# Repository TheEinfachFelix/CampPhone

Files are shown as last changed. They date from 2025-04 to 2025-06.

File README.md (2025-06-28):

# CampPhone

https://wolles-elektronikkiste.de/sim800l-modul

Gruppen Anruf
https://stackoverflow.com/questions/60790790/how-can-i-start-a-conference-call-on-gsm-network

Datasheet
https://www.makershop.de/download/Datasheet_SIM800L.pdf

Infos zu sim800L
https://dasraspberrypi.de/sim800l-gsm-gps-raspberry-4/

Sim 1:  4915756785137

Warum habe ich mich dagegen entschieden, das Sim Modul selber zu implementieren? Ich habe kein Chip gefunden, der günstiger als das fertige Modul war, und ein Datenblatt in Englischer Sprache hat.

GPS Module:
https://www.lcsc.com/product-detail/GNSS-Modules_ZHONGKEWEI-ATGM336H-5N31_C90770.html

Doku Dazu
https://medium.com/@joshhrisko/portable-gps-tracker-with-arduino-3affead7ba12
Ne lib dazu
https://github.com/mikalhart/TinyGPSPlus

Zum Display
https://buyepaper.com/products/27-inch-e-ink-touch-screen-spi-interface-4-grayscale-gdey027t91-t01
https://de.aliexpress.com/item/1005004887416350.html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!!!

Daten
https://www.good-display.com/product/259.html

FT6336U Touch Chip

Hier ne lib fürs display
https://github.com/ZinggJM/GxEPD2

Und fürs Touch
https://github.com/aselectroworks/Arduino-FT6336U

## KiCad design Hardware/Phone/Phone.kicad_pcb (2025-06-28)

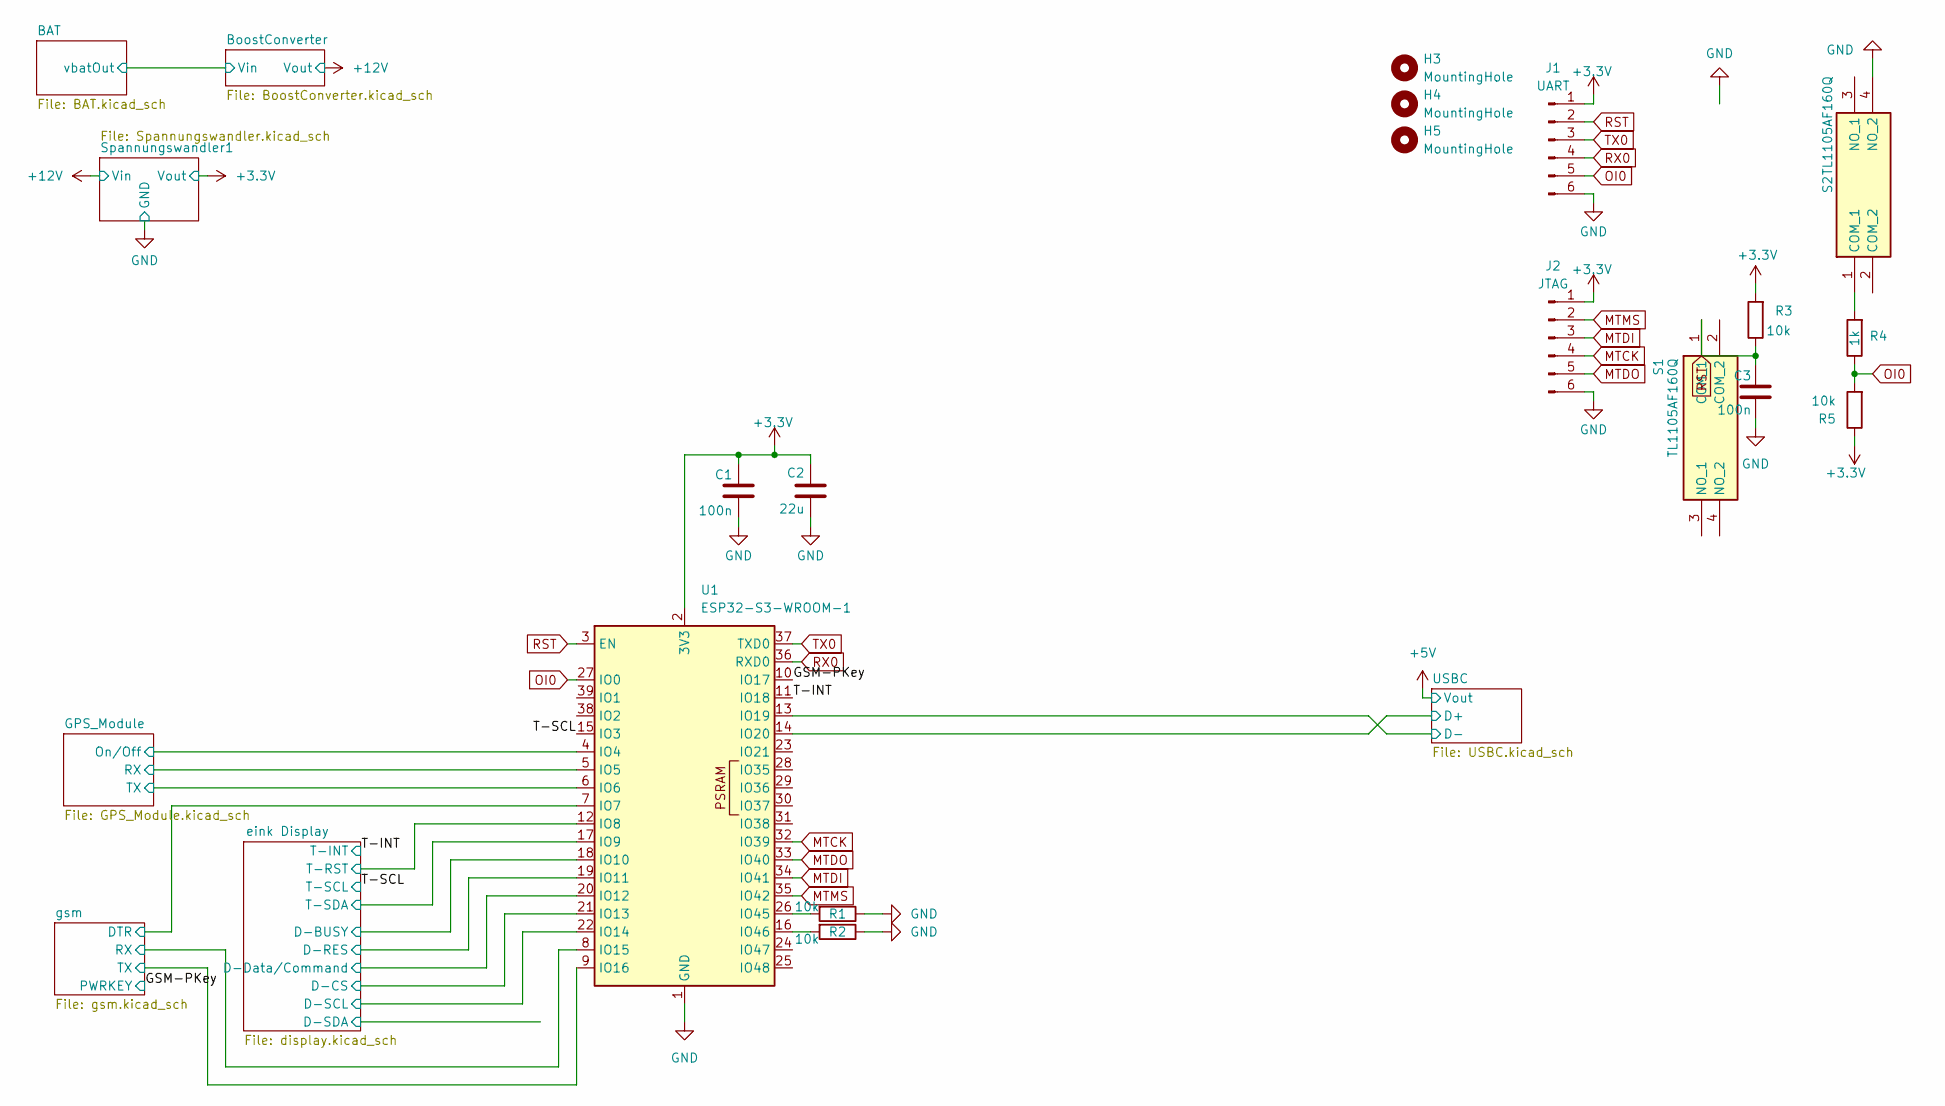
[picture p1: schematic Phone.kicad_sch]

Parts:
C1, C3: 100n; C_0603_1608Metric
C2: 22u; C_0603_1608Metric
H3, H4, H5: MountingHole; MountingHole_3.2mm_M3
J1: UART; 490107670612
J2: JTAG; 490107670612
R1, R2, R3, R5: 10k; R_0603_1608Metric
R4: 1k; R_0603_1608Metric
S1, S2: TL1105AF160Q; Mouser Part Number 612-TL1105A
U1: ESP32-S3-WROOM-1; ESP32-S3-WROOM-1U

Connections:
+3.3V: C1.2, C2.2, J1.1, J2.1, R3.2, R5.1, U1.2 (3V3); also elsewhere on the board
/GPS_Module/On/Off: U1.4 (IO4); also elsewhere on the board
/GPS_Module/RX: U1.5 (IO5); also elsewhere on the board
/GPS_Module/TX: U1.6 (IO6); also elsewhere on the board
/GSM-PKey: U1.10 (IO17); also elsewhere on the board
/T-INT: U1.11 (IO18); also elsewhere on the board
/T-SCL: U1.15 (IO3); also elsewhere on the board
/USBC/D+: U1.14 (IO20); also elsewhere on the board
/USBC/D-: U1.13 (IO19); also elsewhere on the board
/eink Display/D-BUSY: U1.18 (IO10); also elsewhere on the board
/eink Display/D-CS: U1.21 (IO13); also elsewhere on the board
/eink Display/D-Data/Command: U1.20 (IO12); also elsewhere on the board
/eink Display/D-RES: U1.19 (IO11); also elsewhere on the board
/eink Display/D-SCL: U1.22 (IO14); also elsewhere on the board
/eink Display/T-RST: U1.12 (IO8); also elsewhere on the board
/eink Display/T-SDA: U1.17 (IO9); also elsewhere on the board
/gsm/DTR: U1.7 (IO7); also elsewhere on the board
/gsm/RX: U1.8 (IO15); also elsewhere on the board
/gsm/TX: U1.9 (IO16); also elsewhere on the board
GND: C1.1, C2.1, C3.1, J1.6, J2.6, R1.1, R2.1, S2.4 (NO_2), U1.1 (GND), U1.40 (GND), U1.41 (GND); also elsewhere on the board
MTCK: J2.4, U1.32 (IO39)
MTDI: J2.3, U1.34 (IO41)
MTDO: J2.5, U1.33 (IO40)
MTMS: J2.2, U1.35 (IO42)
unnamed: R4.2, S2.1 (COM_1)
unnamed: R1.2, U1.26 (IO45)
unnamed: R2.2, U1.16 (IO46)
OI0: J1.5, R4.1, R5.2, U1.27 (IO0)
RST: C3.2, J1.2, R3.1, S1.1 (COM_1), U1.3 (EN)
RX0: J1.4, U1.36 (RXD0)
TX0: J1.3, U1.37 (TXD0)

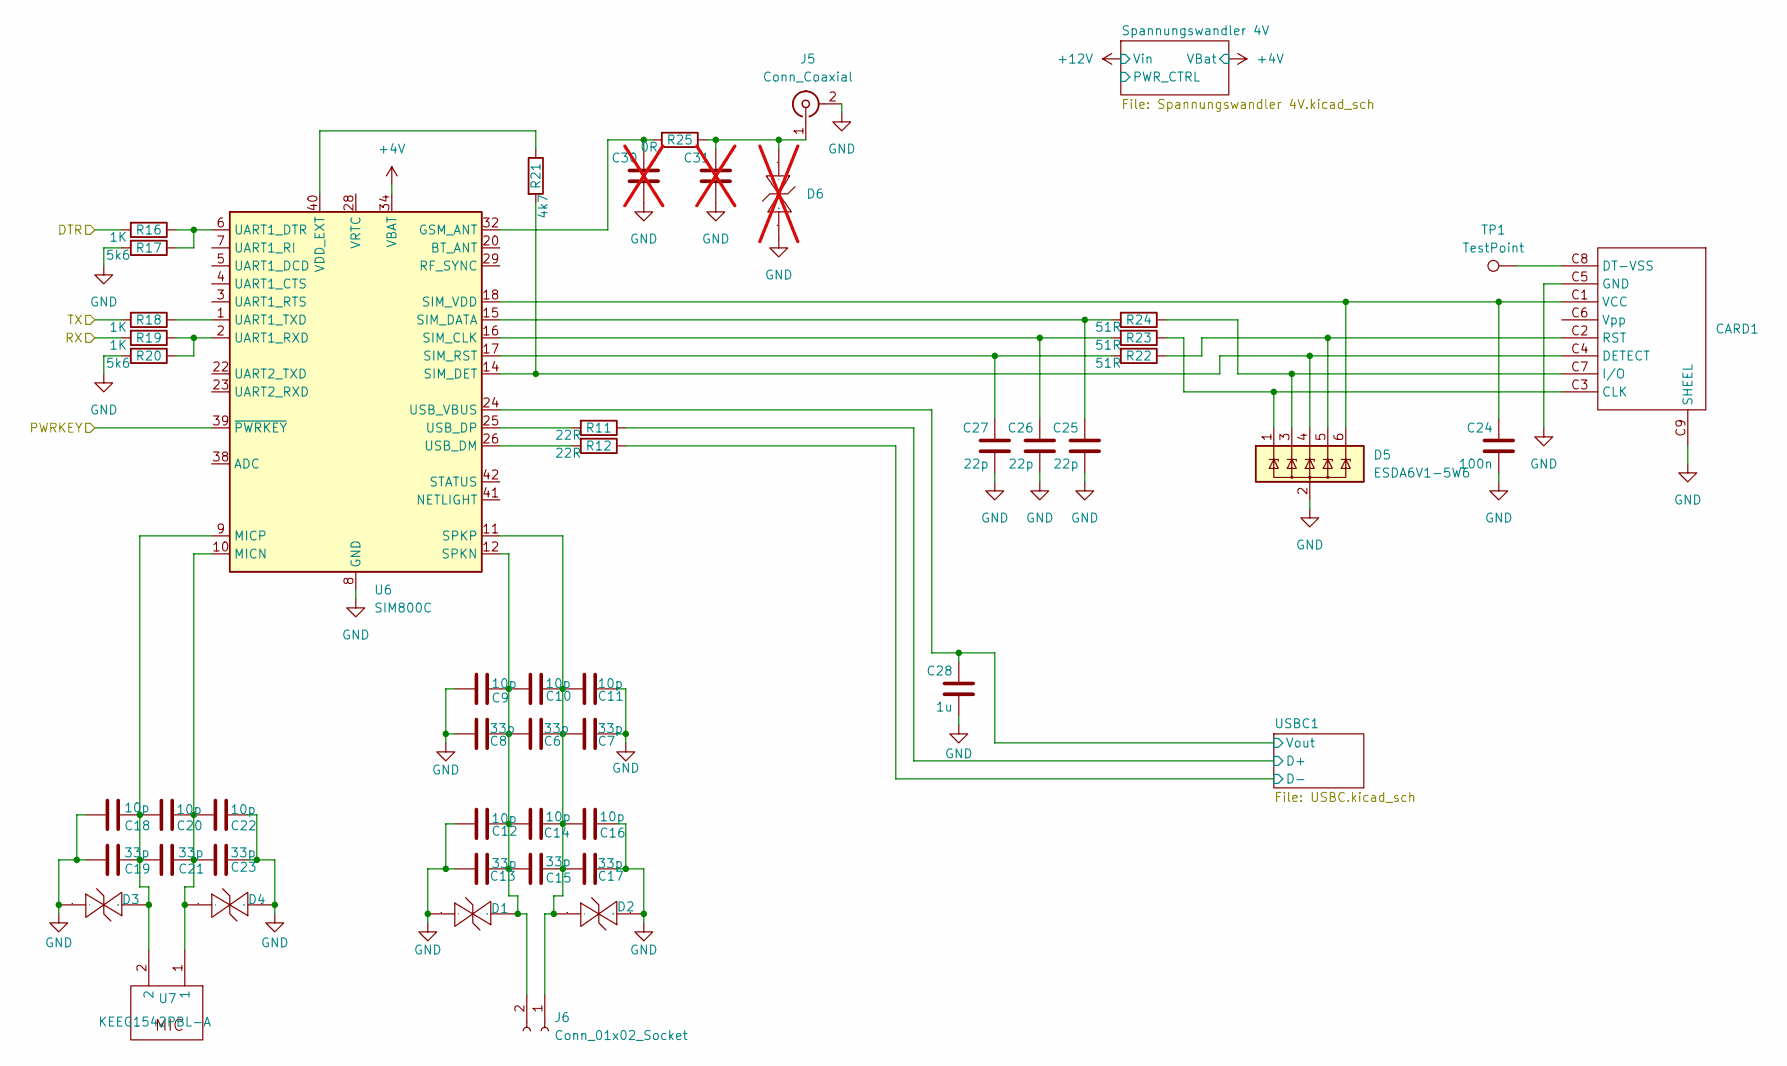
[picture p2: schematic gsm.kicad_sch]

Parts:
C6, C7, C8, C13, C15, C17, C19, C21, C23: 33p; C_0603_1608Metric
C9, C10, C11, C12, C14, C16, C18, C20, C22: 10p; C_0603_1608Metric
C24: 100n; C_0603_1608Metric
C25, C26, C27: 22p; C_0603_1608Metric
C28: 1u; C_0603_1608Metric
C30, C31: C_0603_1608Metric; not fitted
CARD1: SIM-SMD_503960-0696
D1, D2, D3, D4: SOD-882_L1.0-W0.6-BI
D5: ESDA6V1-5W6; SOT-363_SC-70-6
D6: SOD-882_L1.0-W0.6-BI; not fitted
J5: Conn_Coaxial; U.FL_Hirose_U.FL-R-SMT-1_Vertical
J6: Conn_01x02_Socket; PinHeader_1x02_P2.54mm_Vertical
R11, R12: 22R; R_0603_1608Metric
R16, R18, R19: 1K; R_0603_1608Metric
R17, R20: 5k6; R_0603_1608Metric
R21: 4k7; R_0603_1608Metric
R22, R23, R24: 51R; R_0603_1608Metric
R25: 0R; R_0603_1608Metric
TP1: TestPoint; TestPoint_Pad_D1.0mm
U6: SIM800C; SIMCom_SIM800C
U7: KEEG1542PBL-A; MIC-TH_BD4.0-P1.40_KEEG1542PBL-A

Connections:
+4V: U6.34 (VBAT), U6.35 (VBAT); also elsewhere on the board
/GSM-PKey: U6.39 (~PWRKEY); also elsewhere on the board
/gsm/DTR: R16.2; also elsewhere on the board
/gsm/RX: R19.2; also elsewhere on the board
/gsm/TX: R18.2; also elsewhere on the board
/gsm/USBC1/D+: R11.1; also elsewhere on the board
/gsm/USBC1/D-: R12.1; also elsewhere on the board
/gsm/USBC1/Vout: C28.2, U6.24 (USB_VBUS); also elsewhere on the board
GND: C7.1, C8.2, C9.2, C11.1, C12.2, C13.2, C16.1, C17.1, C18.2, C19.2, C22.1, C23.1, C24.1, C25.1, C26.1, C27.1, C28.1, C30.1, C31.1, CARD1.C5 (GND), CARD1.C9 (SHEEL), D1.1 (C), D2.2 (A), D3.1 (C), D4.2 (A), D5.2 (GND), D6.2 (A), J5.2 (Ext), R17.2, R20.2, U6.8 (GND), U6.13 (GND), U6.19 (GND), U6.21 (GND), U6.27 (GND), U6.30 (GND), U6.31 (GND), U6.33 (GND), U6.36 (GND), U6.37 (GND); also elsewhere on the board
unnamed: CARD1.C3 (CLK), D5.1 (IO1), R23.1
unnamed: CARD1.C4 (DETECT), D5.4 (IO3), R21.2, U6.14 (SIM_DET)
unnamed: CARD1.C8 (DT-VSS), TP1.1
unnamed: CARD1.C7 (I/O), D5.3 (IO2), R24.1
unnamed: CARD1.C2 (RST), D5.5 (IO4), R22.1
unnamed: C24.2, CARD1.C1 (VCC), D5.6 (IO5), U6.18 (SIM_VDD)
unnamed: C6.2, C8.1, C9.1, C10.2, C12.1, C13.1, C14.2, C15.2, D1.2 (A), J6.2, U6.12 (SPKN)
unnamed: C6.1, C7.2, C10.1, C11.2, C14.1, C15.1, C16.2, C17.2, D2.1 (C), J6.1, U6.11 (SPKP)
unnamed: C18.1, C19.1, C20.2, C21.2, D3.2 (A), U6.9 (MICP), U7.2
unnamed: C20.1, C21.1, C22.2, C23.2, D4.1 (C), U6.10 (MICN), U7.1
unnamed: C31.2, D6.1 (C), J5.1 (In), R25.1
unnamed: C30.2, R25.2, U6.32 (GSM_ANT)
unnamed: C26.2, R23.2, U6.16 (SIM_CLK)
unnamed: C25.2, R24.2, U6.15 (SIM_DATA)
unnamed: C27.2, R22.2, U6.17 (SIM_RST)
unnamed: R16.1, R17.1, U6.6 (UART1_DTR)
unnamed: R19.1, R20.1, U6.2 (UART1_RXD)
unnamed: R18.1, U6.1 (UART1_TXD)
unnamed: R12.2, U6.26 (USB_DM)
unnamed: R11.2, U6.25 (USB_DP)
unnamed: R21.1, U6.40 (VDD_EXT)

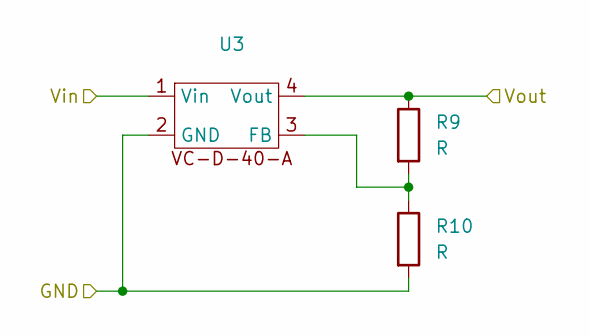
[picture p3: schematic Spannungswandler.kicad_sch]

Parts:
R9, R10: R; R_0805_2012Metric_Pad1.20x1.40mm_HandSolder
U3: VC-D-40-A

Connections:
+3.3V: R9.1, U3.4 (Vout); also elsewhere on the board
+12V: U3.1 (Vin); also elsewhere on the board
GND: R10.2, U3.2 (GND); also elsewhere on the board
unnamed: R9.2, R10.1, U3.3 (FB)

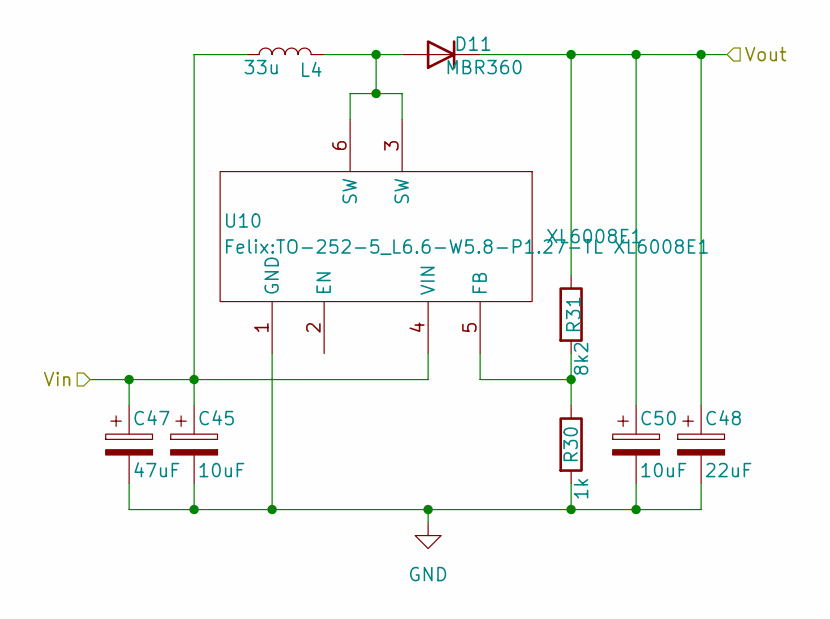
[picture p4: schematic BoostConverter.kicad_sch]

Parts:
C45, C50: 10uF; CP_Elec_4x5.4
C47: 47uF; CP_Elec_6.3x7.7
C48: 22uF; CP_Elec_10x10
D11: MBR360; TO-252-2
L4: 33u; L_7.3x7.3_H4.5
R30: 1k; R_0603_1608Metric
R31: 8k2; R_0603_1608Metric
U10: XL6008E1; TO-252-5_L6.6-W5.8-P1.27-TL XL6008E1

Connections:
+12V: C48.1, C50.1, D11.1 (K), R31.1; also elsewhere on the board
/BAT/vbatOut: C45.1, C47.1, L4.1, U10.4 (VIN); also elsewhere on the board
GND: C45.2, C47.2, C48.2, C50.2, R30.2, U10.1 (GND); also elsewhere on the board
unnamed: D11.2 (A), L4.2, U10.3 (SW), U10.6 (SW)
unnamed: R30.1, R31.2, U10.5 (FB)

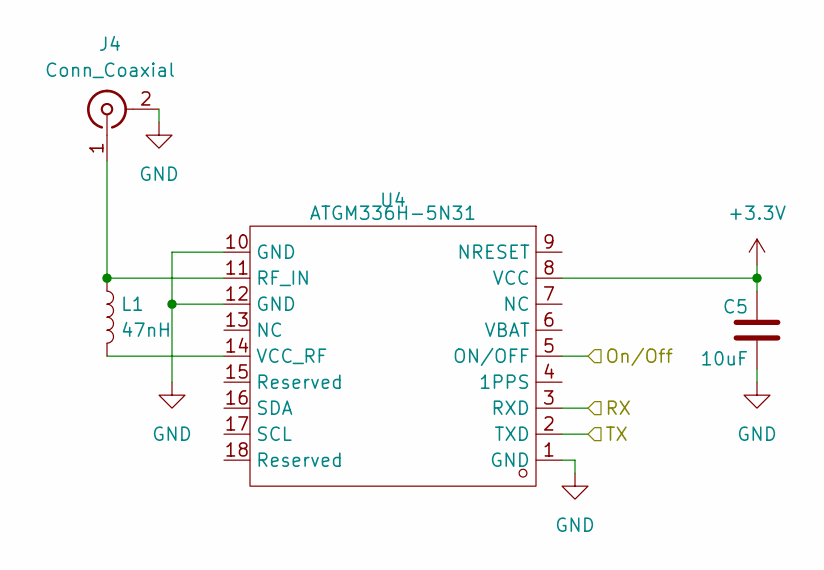
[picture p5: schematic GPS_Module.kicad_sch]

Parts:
C5: 10uF; C_0603_1608Metric
J4: Conn_Coaxial; U.FL_Hirose_U.FL-R-SMT-1_Vertical
L1: 47nH; L_0805_2012Metric
U4: ATGM336H-5N31; GPSM-SMD_ATGM336H-TR

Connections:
+3.3V: C5.2, U4.8 (VCC); also elsewhere on the board
/GPS_Module/On/Off: U4.5 (ON/OFF); also elsewhere on the board
/GPS_Module/RX: U4.3 (RXD); also elsewhere on the board
/GPS_Module/TX: U4.2 (TXD); also elsewhere on the board
GND: C5.1, J4.2 (Ext), U4.1 (GND), U4.10 (GND), U4.12 (GND); also elsewhere on the board
unnamed: J4.1 (In), L1.1, U4.11 (RF_IN)
unnamed: L1.2, U4.14 (VCC_RF)

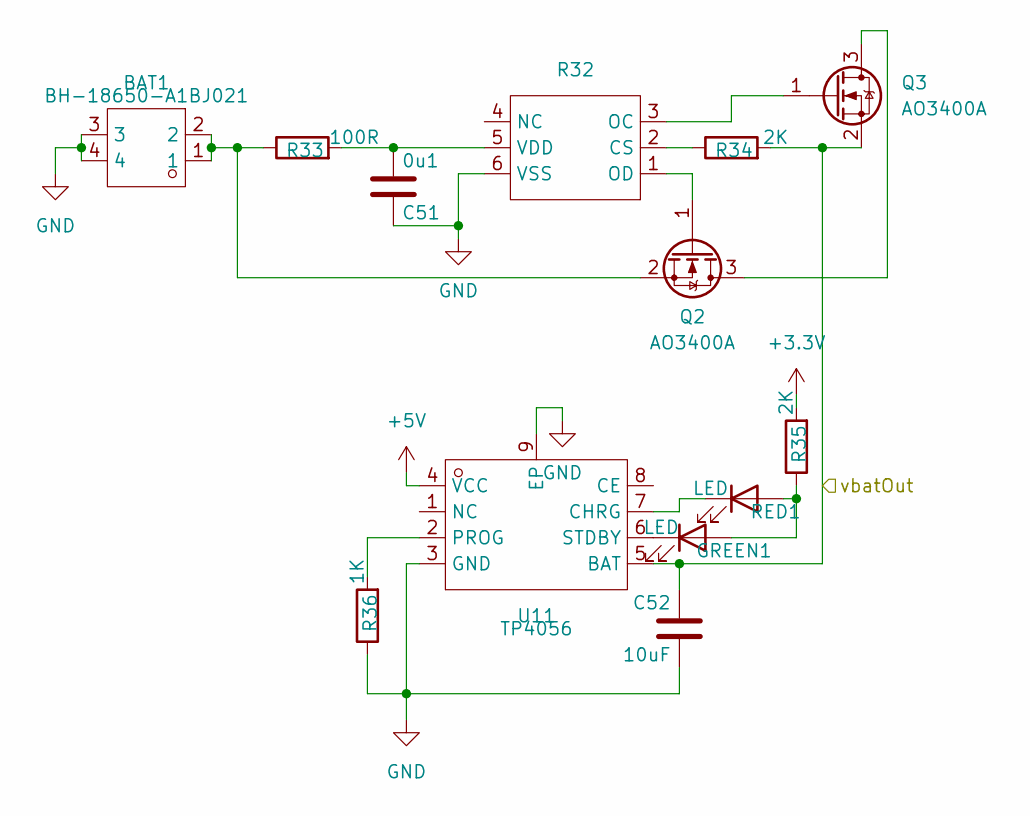
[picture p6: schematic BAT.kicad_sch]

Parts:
BAT1: BH-18650-A1BJ021; BAT-TH_L77.0-W39.9_BH-18650-A1BJ021
C51: 0u1; C_0603_1608Metric
C52: 10uF; C_0603_1608Metric
GREEN1: LED; LED_0603_1608Metric
Q2, Q3: AO3400A; SOT-23
R32: SOT-23-6_L2.9-W1.6-P0.95-LS2.8-BR FM2113
R33: 100R; R_0603_1608Metric
R34, R35: 2K; R_0603_1608Metric
R36: 1K; R_0603_1608Metric
RED1: LED; LED_0603_1608Metric
U11: TP4056; ESOP-8_L4.9-W3.9-P1.27-LS6.0-BL-EP

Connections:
+3.3V: R35.2; also elsewhere on the board
+5V: U11.4 (VCC); also elsewhere on the board
/BAT/vbatOut: C52.2, Q3.2 (S), R34.2, U11.5 (BAT); also elsewhere on the board
GND: BAT1.3, BAT1.4, C51.2, C52.1, R32.6 (VSS), R36.1, U11.3 (GND), U11.9 (EP); also elsewhere on the board
unnamed: GREEN1.2 (A), R35.1, RED1.2 (A)
unnamed: GREEN1.1 (K), U11.6 (STDBY)
unnamed: Q2.3 (D), Q3.3 (D)
unnamed: Q2.1 (G), R32.1 (OD)
unnamed: BAT1.1, BAT1.2, Q2.2 (S), R33.1
unnamed: Q3.1 (G), R32.3 (OC)
unnamed: R32.2 (CS), R34.1
unnamed: C51.1, R32.5 (VDD), R33.2
unnamed: RED1.1 (K), U11.7 (CHRG)
unnamed: R36.2, U11.2 (PROG)

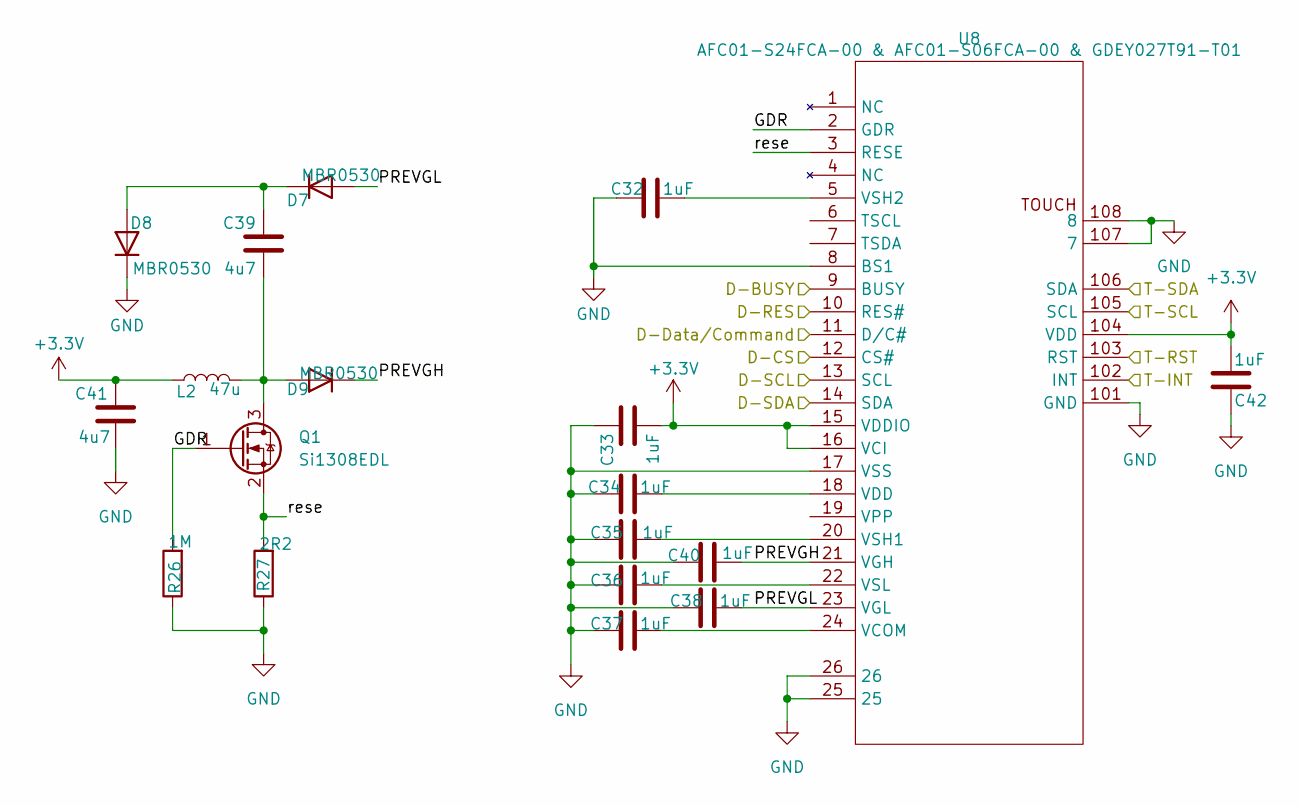
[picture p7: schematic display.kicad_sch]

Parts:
C32, C33, C34, C35, C36, C37, C38, C40, C42: 1uF; C_0603_1608Metric
C39, C41: 4u7; C_0603_1608Metric
D7, D8, D9: MBR0530; D_SOD-123
L2: 47u; IND-SMD_L4.0-W4.0 MNR4012
Q1: Si1308EDL; SOT-323_SC-70
R26: 1M; R_0603_1608Metric
R27: 2R2; R_0603_1608Metric
U8: AFC01-S24FCA-00 & AFC01-S06FCA-00 & GDEY027T91-T01; GDEY027T91-T01 Eink Touch LONG

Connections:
+3.3V: C33.1, C41.2, C42.1, L2.1, U8.15 (VDDIO), U8.16 (VCI), U8.104 (VDD); also elsewhere on the board
/T-INT: U8.102 (INT); also elsewhere on the board
/T-SCL: U8.105 (SCL); also elsewhere on the board
/eink Display/D-BUSY: U8.9 (BUSY); also elsewhere on the board
/eink Display/D-CS: U8.12 (CS#); also elsewhere on the board
/eink Display/D-Data/Command: U8.11 (D/C#); also elsewhere on the board
/eink Display/D-RES: U8.10 (RES#); also elsewhere on the board
/eink Display/D-SCL: U8.13 (SCL); also elsewhere on the board
/eink Display/D-SDA: U8.14 (SDA)
/eink Display/GDR: Q1.1 (G), R26.2, U8.2 (GDR)
/eink Display/PREVGH: C40.1, D9.1 (K), U8.21 (VGH)
/eink Display/PREVGL: C38.1, D7.2 (A), U8.23 (VGL)
/eink Display/T-RST: U8.103 (RST); also elsewhere on the board
/eink Display/T-SDA: U8.106 (SDA); also elsewhere on the board
/eink Display/rese: Q1.2 (S), R27.2, U8.3 (RESE)
GND: C32.2, C33.2, C34.2, C35.2, C36.2, C37.2, C38.2, C40.2, C41.1, C42.2, D8.1 (K), R26.1, R27.1, U8.8 (BS1), U8.17 (VSS), U8.25, U8.26, U8.101 (GND), U8.107 (7), U8.108 (8); also elsewhere on the board
unnamed: C34.1, U8.18 (VDD)
unnamed: C39.2, D7.1 (K), D8.2 (A)
unnamed: C39.1, D9.2 (A), L2.2, Q1.3 (D)
unnamed: C37.1, U8.24 (VCOM)
unnamed: C35.1, U8.20 (VSH1)
unnamed: C32.1, U8.5 (VSH2)
unnamed: C36.1, U8.22 (VSL)

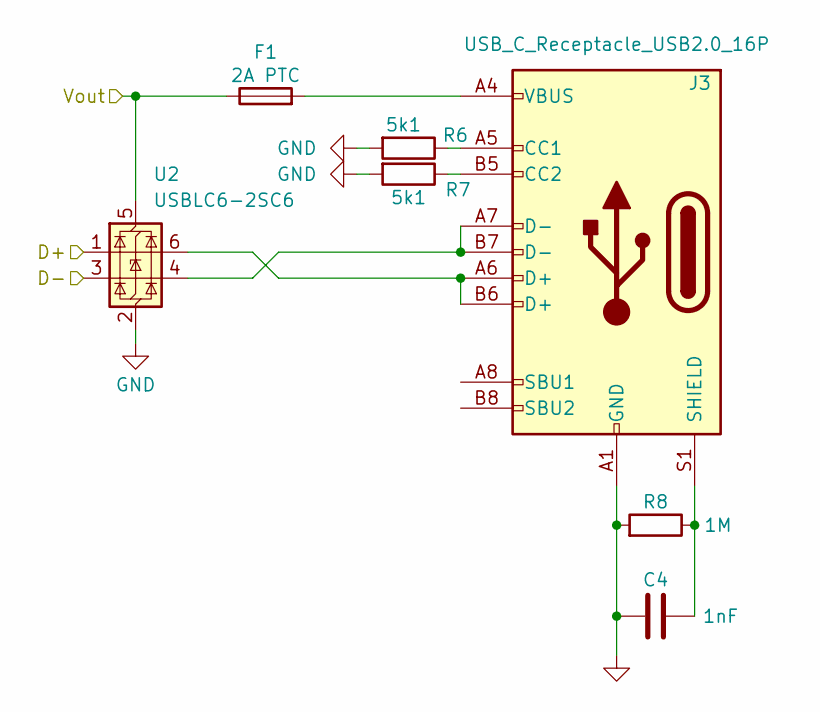
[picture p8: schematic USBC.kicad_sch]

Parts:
C4: 1nF; C_1206_3216Metric
F1: 2A PTC; Fuse_1206_3216Metric_Pad1.42x1.75mm_HandSolder
J3: USB_C_Receptacle_USB2.0_16P; USB_C_Receptacle_HRO_TYPE-C-31-M-12
R6, R7: 5k1; R_1206_3216Metric
R8: 1M; R_1206_3216Metric
U2: USBLC6-2SC6; SOT-23-6

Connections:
+5V: F1.1, U2.5 (VBUS); also elsewhere on the board
/USBC/D+: U2.1 (I/O1); also elsewhere on the board
/USBC/D-: U2.3 (I/O2); also elsewhere on the board
GND: C4.2, J3.A1 (GND), J3.A12 (GND), J3.B1 (GND), J3.B12 (GND), R6.2, R7.2, R8.2, U2.2 (GND); also elsewhere on the board
unnamed: F1.2, J3.A4 (VBUS), J3.A9 (VBUS), J3.B4 (VBUS), J3.B9 (VBUS)
unnamed: J3.A5 (CC1), R6.1
unnamed: J3.B5 (CC2), R7.1
unnamed: J3.A6 (D+), J3.B6 (D+), U2.6 (I/O1)
unnamed: J3.A7 (D-), J3.B7 (D-), U2.4 (I/O2)
unnamed: C4.1, J3.S1 (SHIELD), R8.1

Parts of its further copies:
C53: 1nF; C_1206_3216Metric
F3: 2A PTC; Fuse_1206_3216Metric_Pad1.42x1.75mm_HandSolder
J8: USB_C_Receptacle_USB2.0_16P; USB_C_Receptacle_HRO_TYPE-C-31-M-12
R37, R38: 5k1; R_1206_3216Metric
R39: 1M; R_1206_3216Metric
U12: USBLC6-2SC6; SOT-23-6

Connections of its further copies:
/gsm/USBC1/D+: U12.1 (I/O1); also elsewhere on the board
/gsm/USBC1/D-: U12.3 (I/O2); also elsewhere on the board
/gsm/USBC1/Vout: F3.1, U12.5 (VBUS); also elsewhere on the board
GND: C53.2, J8.A1 (GND), J8.A12 (GND), J8.B1 (GND), J8.B12 (GND), R37.2, R38.2, R39.2, U12.2 (GND); also elsewhere on the board
unnamed: F3.2, J8.A4 (VBUS), J8.A9 (VBUS), J8.B4 (VBUS), J8.B9 (VBUS)
unnamed: J8.A5 (CC1), R37.1
unnamed: J8.B5 (CC2), R38.1
unnamed: J8.A6 (D+), J8.B6 (D+), U12.6 (I/O1)
unnamed: J8.A7 (D-), J8.B7 (D-), U12.4 (I/O2)
unnamed: C53.1, J8.S1 (SHIELD), R39.1

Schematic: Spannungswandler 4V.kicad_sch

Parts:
C43: 330u; C_Elec_6.3x7.7
C44: 1u; C_0603_1608Metric
C46: 100n; C_0603_1608Metric
C49: 100u; C_Elec_8x10.2
D10: MBR360; TO-252-2
FB1: FerriteBead 270R @ 100Mhz; L_1206_3216Metric
L3: 100u; IND-SMD_L10.6-W10.2 2A 11x10mm
R28: 2k2; R_0603_1608Metric
R29: 1k; R_0603_1608Metric
U9: LM2596S-ADJ; TO-263-5_TabPin3

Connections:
+4V: FB1.1; also elsewhere on the board
+12V: C44.2, C49.1, U9.1 (VIN); also elsewhere on the board
/gsm/Spannungswandler 4V/PWR_CTRL: U9.5 (~ON/OFF)
GND: C43.2, C44.1, C46.1, C49.2, D10.2 (A), R29.2, U9.3 (GND); also elsewhere on the board
unnamed: C43.1, C46.2, FB1.2, L3.2, R28.1
unnamed: D10.1 (K), L3.1, U9.2 (OUT)
unnamed: R28.2, R29.1, U9.4 (FB)

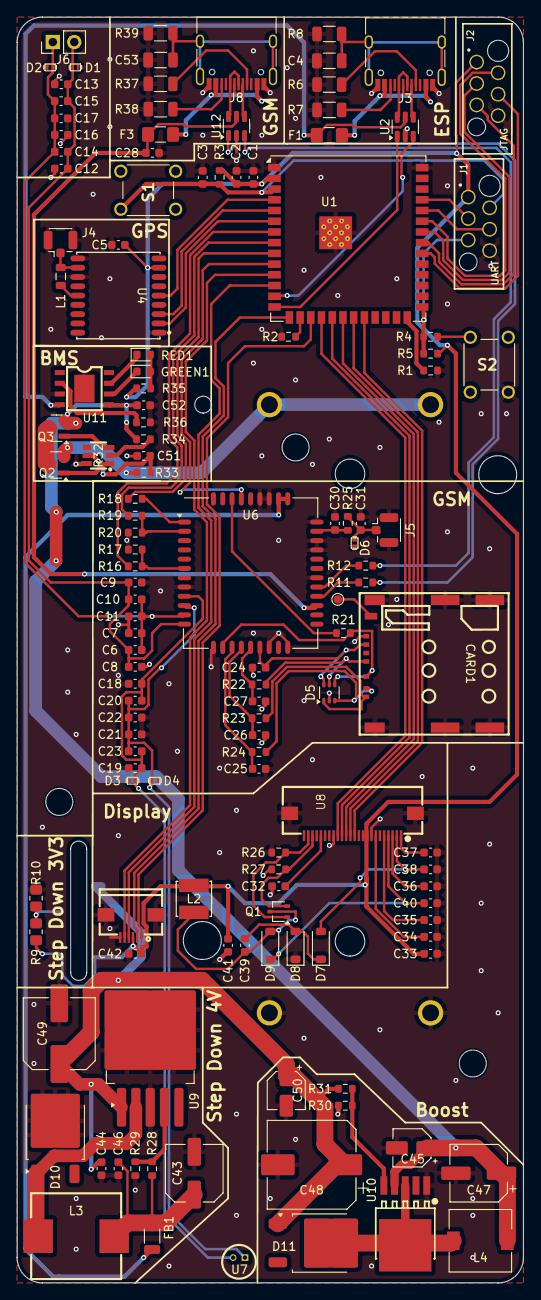
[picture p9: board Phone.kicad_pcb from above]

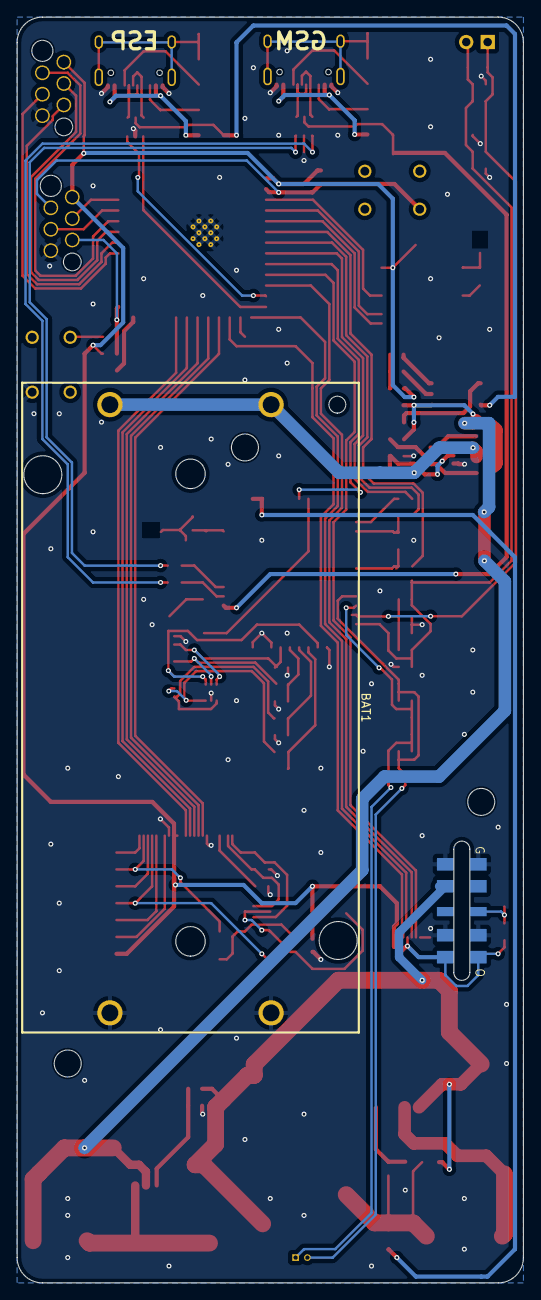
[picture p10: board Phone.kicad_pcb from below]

Board: 2 copper layers, 60.0 x 150.0 mm, 137 parts (2 on the bottom side), 100 nets.

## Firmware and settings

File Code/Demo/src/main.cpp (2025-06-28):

#include <Arduino.h>
#include "Sim800L_Lib\Sim800L.hpp"


#define RX 46
#define TX 9
//#define RX 9
//#define TX 46

Sim800L GSM(RX, TX);

 
void setup() {
  GSM.Debug = true;
  delay(4000);
  Serial.begin(9600);
  GSM.begin();    
  String pin = "2250";
  
  if (GSM.setPIN(pin)) Serial.println("Pin set");
  else 
  {
    do
    {
      Serial.println("Pin ERROR");
      delay(1000);
    } while (GSM.setPIN(pin));
  }

  Serial.println("OK lets Go!");
}

void loop() {
  // put your main code here, to run repeatedly:
  //GSM.checkStatus();
  if (GSM.getCallStatus() == 3) {
    Serial.println("Incoming call...");
    GSM.answerCall();
  }
  delay(300);
}

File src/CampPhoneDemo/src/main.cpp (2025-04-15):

//#include "Sim800L.h"        // Include the library for the SIM800L module
//#include <TinyGsmClient.h>     // Include the library for the TinyGSM client
#include "Sim800L-Arduino-Library-revised/Sim800L.h"
#include <SoftwareSerial.h> 
#include <Arduino.h>              

#define RX  23
#define TX  22

Sim800L GSM(RX, TX);

/*
 * In alternative:
 * Sim800L GSM;                       // Use default pinout
 * Sim800L GSM(RX, TX, RESET);        
 * Sim800L GSM(RX, TX, RESET, LED);
 */

char* text;
char* number;
bool error; 					//to catch the response of sendSms


void setup(){
	GSM.begin(); 			
  GSM.Debug = true; // Enable debug mode to see AT command responses in Serial Monitor
  Serial.begin(9600);

  String pin = "2250";

  if (GSM.setPIN(pin)) Serial.println("Pin set");
  else Serial.println("Pin NOT set");

  delay(8000); //wait for the module to be ready
  //
  Serial.println("get Operator"); //ping the module to check if it is ready
  Serial.println(GSM.getOperator());
	text="Testing Sms";  		//text for the message. 
	number="+4916094842537"; 		//change to a valid number.
	error=GSM.sendSms(number,text);
  Serial.println("Message sent"); //message sent
  Serial.println(error); //error is true if the message was sent, false if not.
	GSM.getCallStatus();

  GSM.callNumber(number);
  Serial.println("call"); //message sent
	// OR 
	//Sim800L.sendSms("+540111111111","the text go here")
  GSM.checkStatus();
}

void loop(){
	//do nothing
}

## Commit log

2025-04-22 started hardware design
    [GPS_Module.kicad_sch, Phone.kicad_pcb, Phone.kicad_sch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]
2025-04-24 e ink is done
    [Phone.kicad_pcb, Phone.kicad_sch, display.kicad_sch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]
2025-04-27 phone design is done abendoning projekt
    [BAT.kicad_sch, BoostConverter.kicad_sch, Phone.kicad_pcb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]
2025-04-27 added doku. Abendoning Projekt
    [BAT.kicad_sch, BoostConverter.kicad_sch, GPS_Module.kicad_sch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]
